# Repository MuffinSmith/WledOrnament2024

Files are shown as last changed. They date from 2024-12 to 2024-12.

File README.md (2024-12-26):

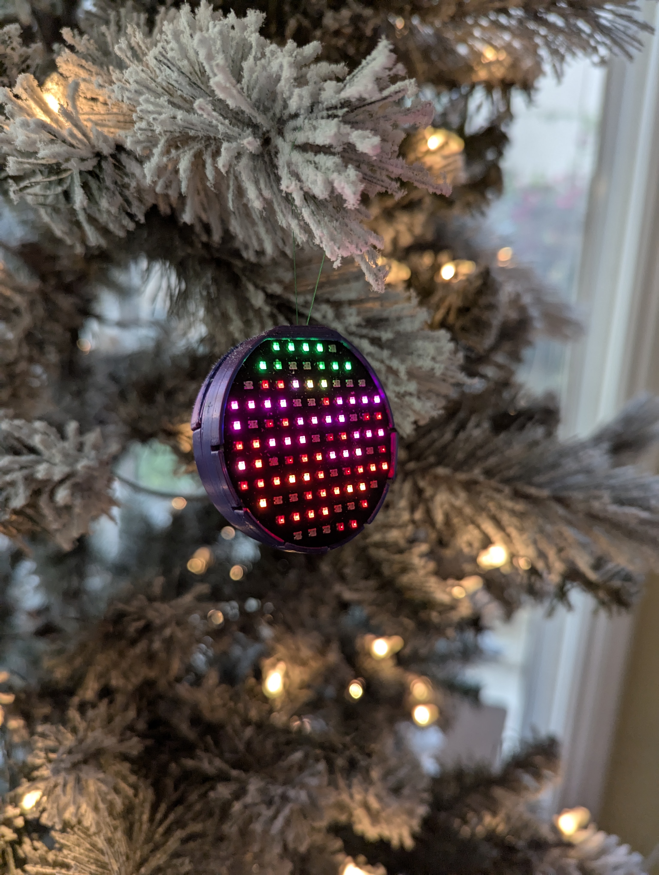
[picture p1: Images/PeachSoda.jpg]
ornament image, Peachsoda effect

# WledOrnament2024
My Christmas present for family
## Instructions
Default behavior is to shuffle all the presets.
Single button press will cycle each preset in order and stay on that preset.
Double button press will go back to shuffling the presets.
Long button press will turn off the display but leave the micro on.

Taking off the back of the ornament starts by holding it from the bottom and
squeezing the corners of the lid with one hand, while pulling at the tab on 
top with the other hand.
To put the lid back on start with the tab and slot it into the groove, then
squeeze the corners of the lid while pushing it back into place.

### Notes for improvement
buttons should be located around the edges 
I want to use soft power to turn on and off the whole device instead of a switch

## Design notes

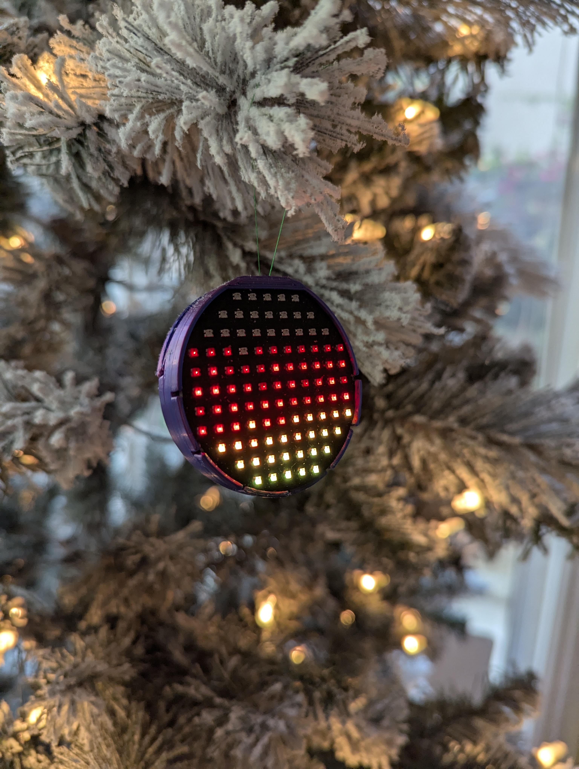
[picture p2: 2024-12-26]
Images/Candle.jpg

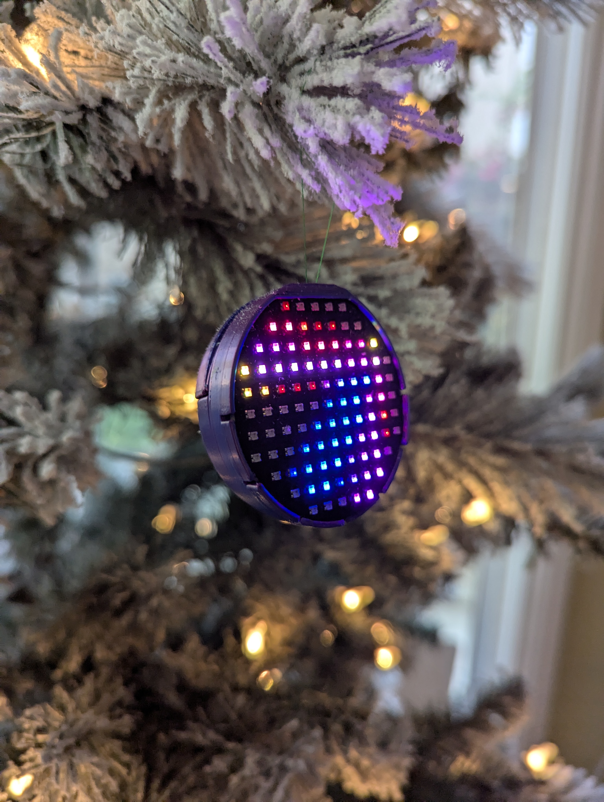
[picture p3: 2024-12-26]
Images/ColorBurst.jpg

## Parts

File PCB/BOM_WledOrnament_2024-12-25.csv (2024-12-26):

No. | Quantity | Comment | Designator | Footprint | Value | Manufacturer Part | Manufacturer | Supplier Part | Supplier
1 | 12 | 100nF | C1,C1,C1,C1,C4,C4,C4,C4,C7,C7,C7,C7 | C0402 | 100nF |  |  | C1525
2 | 20 | 22uF | C2,C2,C2,C2,C8,C8,C8,C8,C9,C9,C9,C9,C10,C10,C10,C10,C11,C11,C11,C11 | C0603 | 22uF | CL10A226MQ8NRNC | SAMSUNG(三星) | C59461 | LCSC
3 | 4 | 10uF | C3,C3,C3,C3 | C0402 | 10uF | CL05A106MQ5NUNC | SAMSUNG(三星) | C15525 | LCSC
4 | 8 | 2.2uF | C5,C5,C5,C5,C12,C12,C12,C12 | C0402 | 2.2uF | CL05A225MQ5NSNC | SAMSUNG(三星) | C12530 | LCSC
5 | 4 | 4.7uF | C6,C6,C6,C6 | C0402 | 4.7uF | CL05A475MP5NRNC | SAMSUNG(三星) | C23733 | LCSC
6 | 4 | SS34 | D1,D1,D1,D1 | SMA_L4.3-W2.6-LS5.2-RD |  | SS34 | MDD(辰达半导体) | C8678 | LCSC
7 | 4 | 4.7uH | L1,L1,L1,L1 | L0805 | 4.7uH | CMP201209UD4R7MT | FH(风华) | C139243 | LCSC
8 | 4 | 1uH | L2,L2,L2,L2 | L1206 | 1uH | CMP321609UD1R0MT | FH(风华) | C139248 | LCSC
9 | 388 | XL-1615RGBC-WS2812B | LED1,LED1,LED1,LED1,LED2,LED2,LED2,LED2,LED3,LED3,LED3,LED3,LED4,LED4,LED4,LED4,LED5,LED5,LED5,LED5,LED6,LED6,LED6,LED6,LED7,LED7,LED7,LED7,LED8,LED8,LED8,LED8,LED9,LED9,LED9,LED9,LED10,LED10,LED10,LED10,LED11,LED11,LED11,LED11,LED12,LED12,LED12,LED12,LED13,LED13,LED13,LED13,LED14,LED14,LED14,LED14,LED15,LED15,LED15,LED15,LED16,LED16,LED16,LED16,LED17,LED17,LED17,LED17,LED18,LED18,LED18,LED18,LED19,LED19,LED19,LED19,LED20,LED20,LED20,LED20,LED21,LED21,LED21,LED21,LED22,LED22,LED22,LED22,LED23,LED23,LED23,LED23,LED24,LED24,LED24,LED24,LED25,LED25,LED25,LED25,LED26,LED26,LED26,LED26,LED27,LED27,LED27,LED27,LED28,LED28,LED28,LED28,LED29,LED29,LED29,LED29,LED30,LED30,LED30,LED30,LED31,LED31,LED31,LED31,LED32,LED32,LED32,LED32,LED33,LED33,LED33,LED33,LED34,LED34,LED34,LED34,LED35,LED35,LED35,LED35,LED36,LED36,LED36,LED36,LED37,LED37,LED37,LED37,LED38,LED38,LED38,LED38,LED39,LED39,LED39,LED39,LED40,LED40,LED40,LED40,LED41,LED41,LED41,LED41,LED42,LED42,LED42,LED42,LED43,LED43,LED43,LED43,LED44,LED44,LED44,LED44,LED45,LED45,LED45,LED45,LED46,LED46,LED46,LED46,LED47,LED47,LED47,LED47,LED48,LED48,LED48,LED48,LED49,LED49,LED49,LED49,LED50,LED50,LED50,LED50,LED51,LED51,LED51,LED51,LED52,LED52,LED52,LED52,LED53,LED53,LED53,LED53,LED54,LED54,LED54,LED54,LED55,LED55,LED55,LED55,LED56,LED56,LED56,LED56,LED57,LED57,LED57,LED57,LED58,LED58,LED58,LED58,LED59,LED59,LED59,LED59,LED60,LED60,LED60,LED60,LED61,LED61,LED61,LED61,LED62,LED62,LED62,LED62,LED63,LED63,LED63,LED63,LED64,LED64,LED64,LED6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 | LED-SMD_4P-L1.6-W1.5_XL-1615RGBC-WS2812B |  | XL-1615RGBC-WS2812B | XINGLIGHT(成兴光) | C5349954 | LCSC
10 | 4 | Mark-Point | MARK1,MARK2,MARK3,MARK4 | Mark-Point-1mm
11 | 4 | MMICT390200012 | MIC1,MIC1,MIC1,MIC1 | MIC-SMD_5P-L3.5-W2.7-TL_MMICT390200012 |  | MMICT390200012 | TDK InvenSense(应美盛) | C3171752 | LCSC
12 | 4 | Battery Protection | Q1,Q1,Q1,Q1 | SOT-23-6_L2.9-W1.6-P0.95-LS2.8-BR |  | DW01 | Hottech(合科泰) | C181096 | LCSC
13 | 12 | AO3400A | Q2,Q2,Q2,Q2,Q3,Q3,Q3,Q3,Q5,Q5,Q5,Q5 | SOT-23-3_L2.9-W1.3-P1.90-LS2.4-BR |  | AO3400A | AOS | C20917 | LCSC
14 | 4 | S8050 J3Y | Q4,Q4,Q4,Q4 | SOT-23-3_L3.0-W1.7-P0.95-LS2.9-BR |  | S8050 J3Y | CJ(江苏长电/长晶) | C2146 | LCSC
15 | 4 | 2kΩ | R1,R1,R1,R1 | R0402 | 2kΩ | 0402WGF2001TCE | UNI-ROYAL(厚声) | C4109 | LCSC
16 | 4 | 100kΩ | R2,R2,R2,R2 | R0402 | 100kΩ | 0402WGF1003TCE | UNI-ROYAL(厚声) | C25741 | LCSC
17 | 4 | 22kΩ | R3,R3,R3,R3 | R0402 | 22kΩ | 0402WGF2202TCE | UNI-ROYAL(厚声) | C25768 | LCSC
18 | 4 | 100Ω | R4,R4,R4,R4 | R0402 | 100Ω | 0402WGF1000TCE | UNI-ROYAL(厚声) | C25076 | LCSC
19 | 4 | 1kΩ | R5,R5,R5,R5 | R0402 | 1kΩ | 0402WGF1001TCE | UNI-ROYAL(厚声) | C11702 | LCSC
20 | 4 | 10kΩ | R6,R6,R6,R6 | R0402 | 10kΩ | 0402WGF1002TCE | UNI-ROYAL(厚声) | C25744 | LCSC
21 | 4 | On | Off | SW1,SW1,SW1,SW1 | SW-SMD_SS-3235S-L3.00 |  | SS-3235S-L3 | XKB Connectivity(中国星坤) | C381098 | LCSC
22 | 4 | TS-1002S-09026C | SW2,SW2,SW2,SW2 | KEY-SMD_4P-L6.0-W6.0-P4.50-LS9.5-BR |  | TS-1002S-09026C | XUNPU(讯普) | C455118 | LCSC
23 | 4 | ESP32-C3 SuperMini | U1,U1,U1,U1 | ESP32-C3 SuperMini SMT
24 | 4 | Cake Battery | U3,U3,U3,U3 | Cake Battery
25 | 4 | 5v Boost | U5,U5,U5,U5 | WSON-6_L2.0-W2.0-P0.65-TL-EP |  | TPS61240DRVR | TI(德州仪器) | C59567 | LCSC
26 | 4 | Battery charger | U7,U7,U7,U7 | SOT-23-6_L2.9-W1.6-P0.95-LS2.8-BL |  | TP4057 | TPOWER(天源) | C440390 | LCSC
27 | 4 | 3.3 buck | U8,U8,U8,U8 | SOT-23-6_L2.9-W1.6-P0.95-LS2.8-BR |  | SM8102ABC | silergy(矽力杰) | C479069 | LCSC

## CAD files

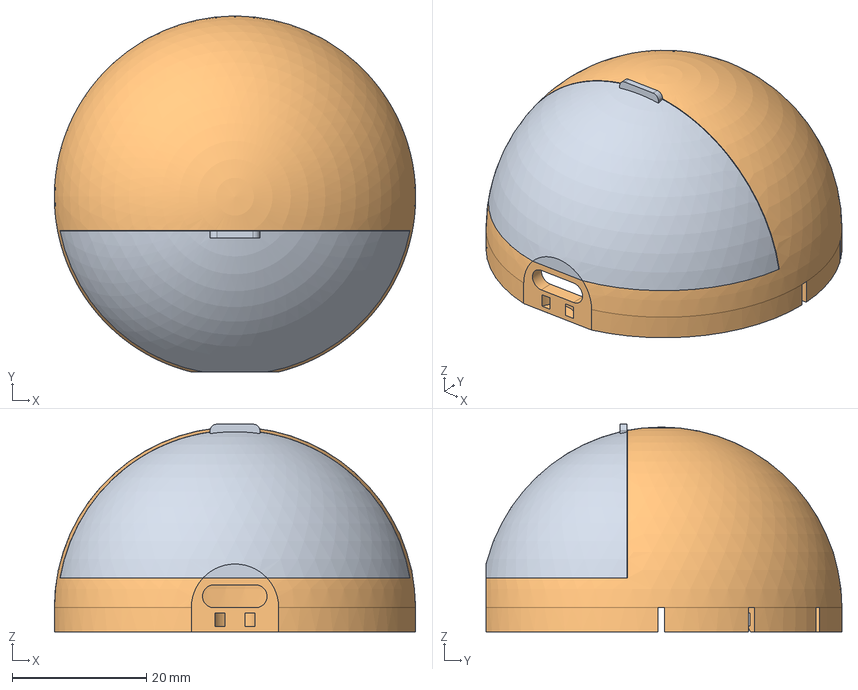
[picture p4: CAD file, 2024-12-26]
3D Files/Ornament Enclosure v15.step
53.8 x 53.0 x 30.9 mm

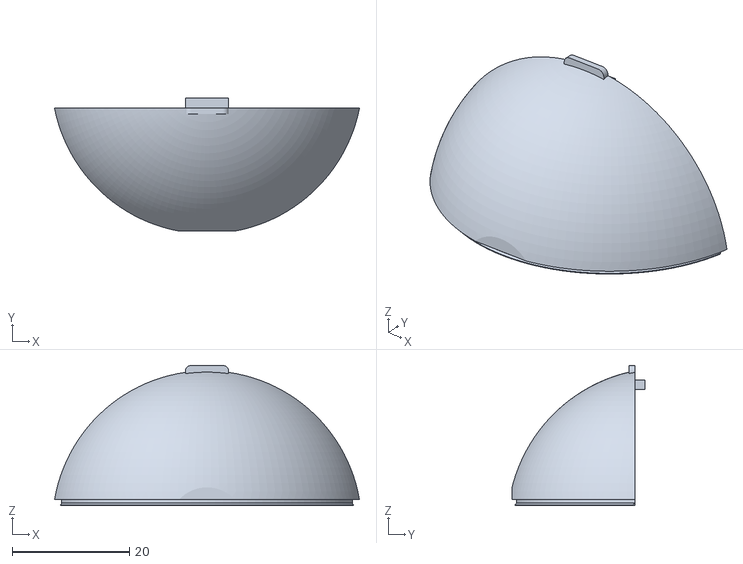
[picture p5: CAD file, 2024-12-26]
3D Files/Ornament Lid.stl
52.0 x 22.7 x 23.9

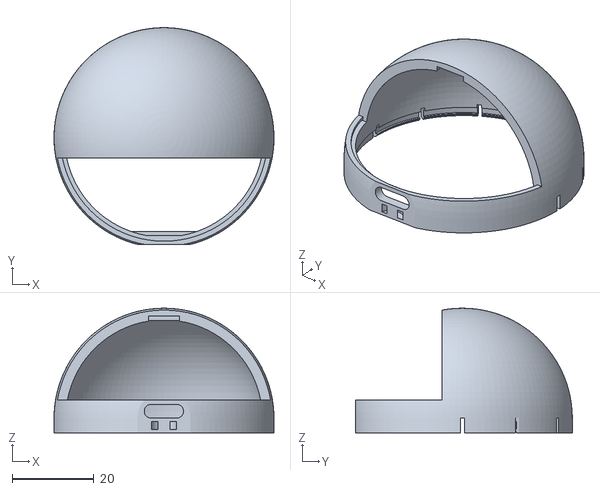
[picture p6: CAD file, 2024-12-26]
3D Files/Ornament Case.stl
53.8 x 53.0 x 30.5

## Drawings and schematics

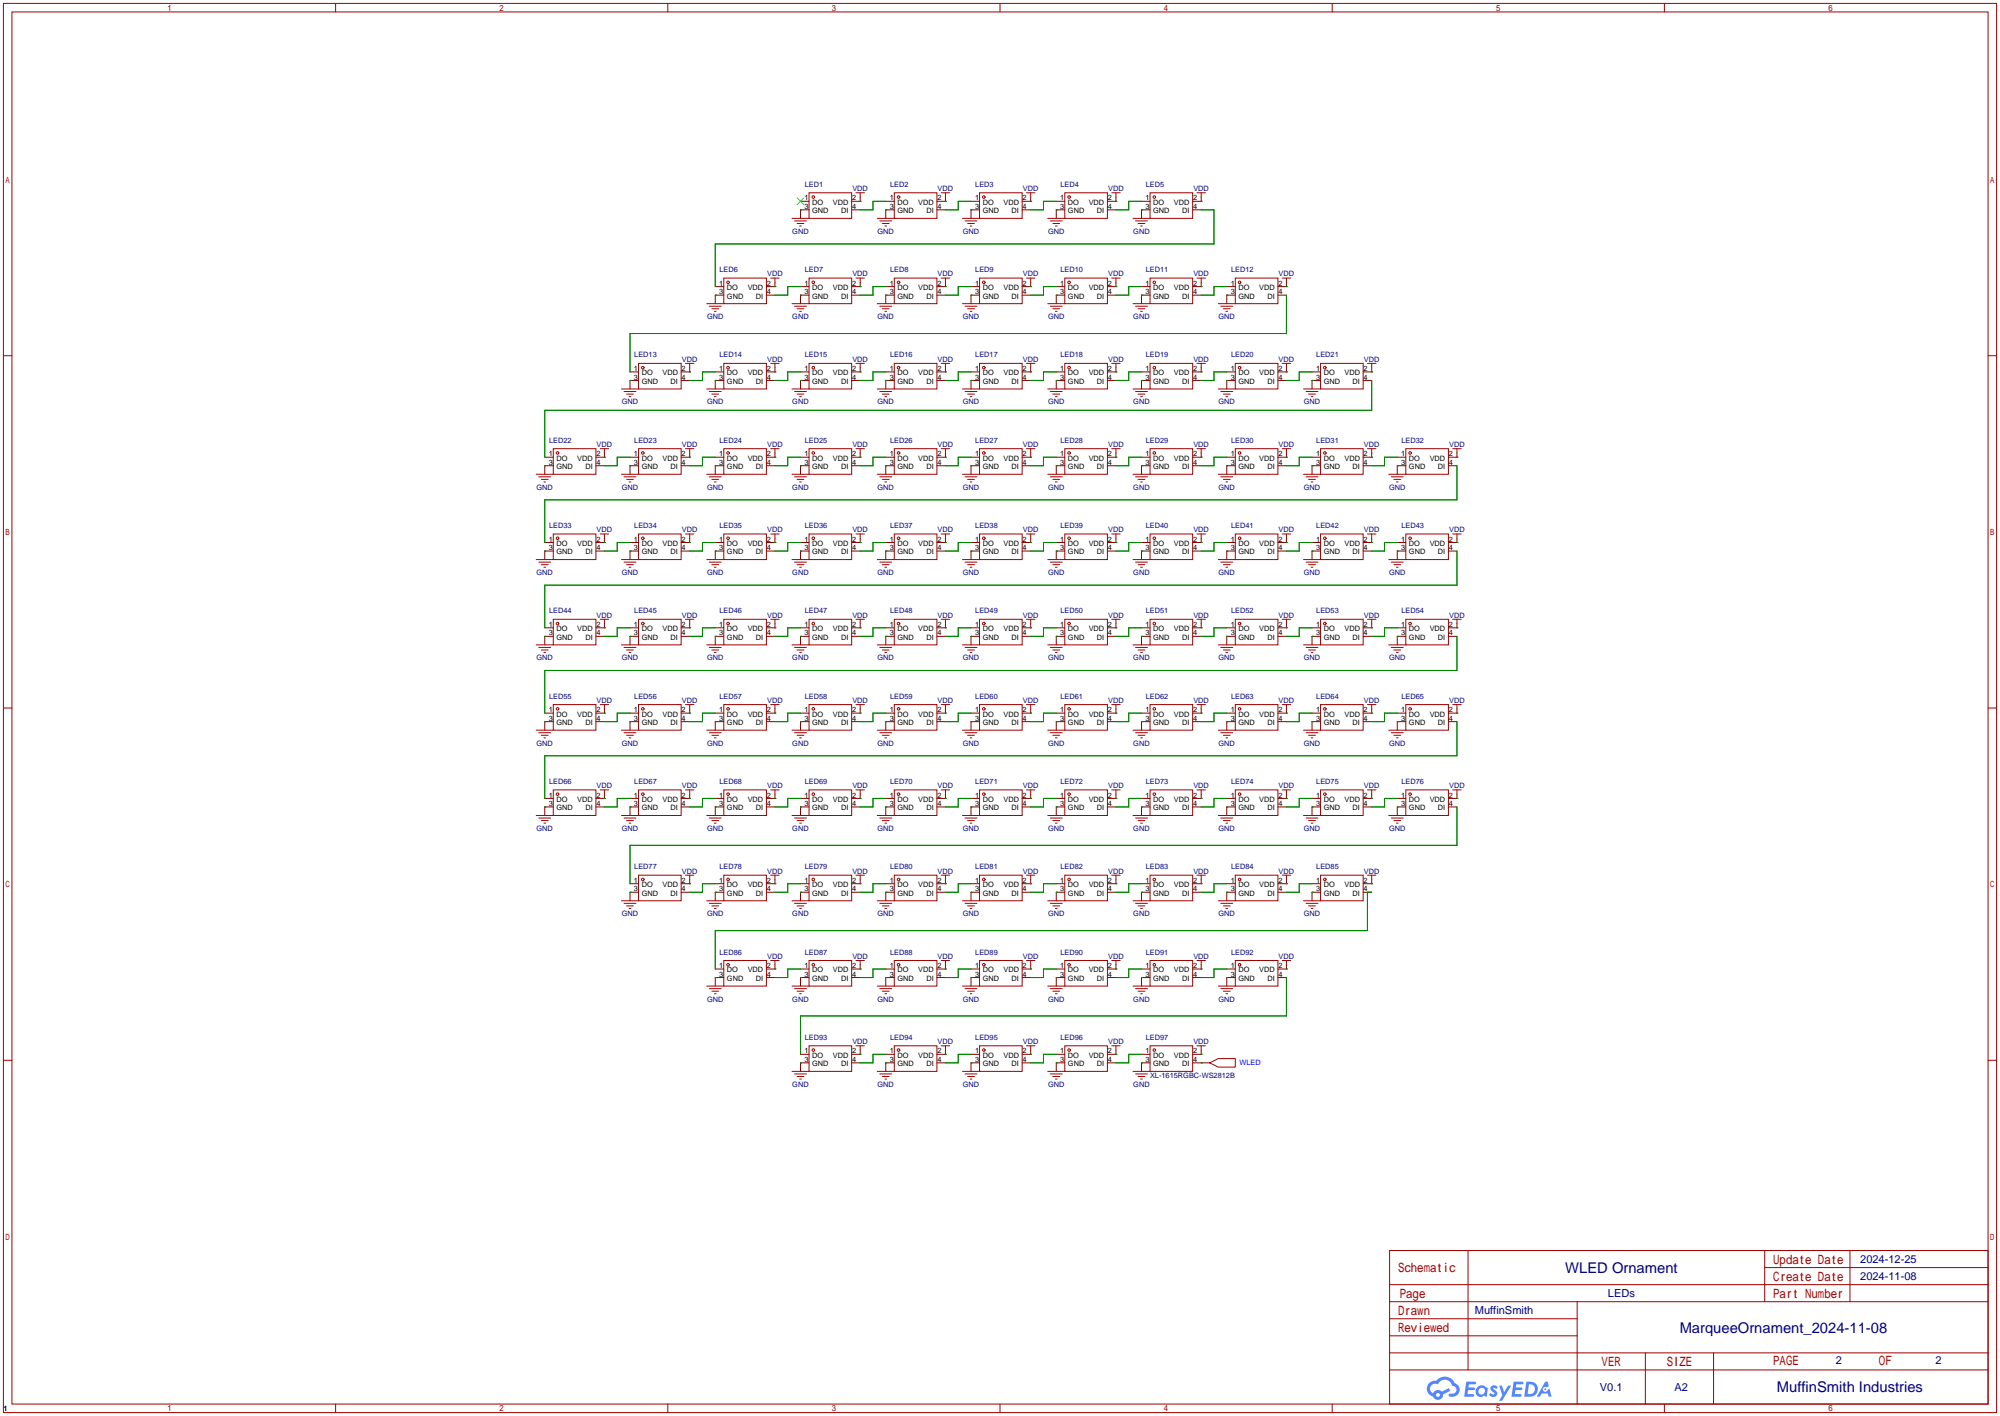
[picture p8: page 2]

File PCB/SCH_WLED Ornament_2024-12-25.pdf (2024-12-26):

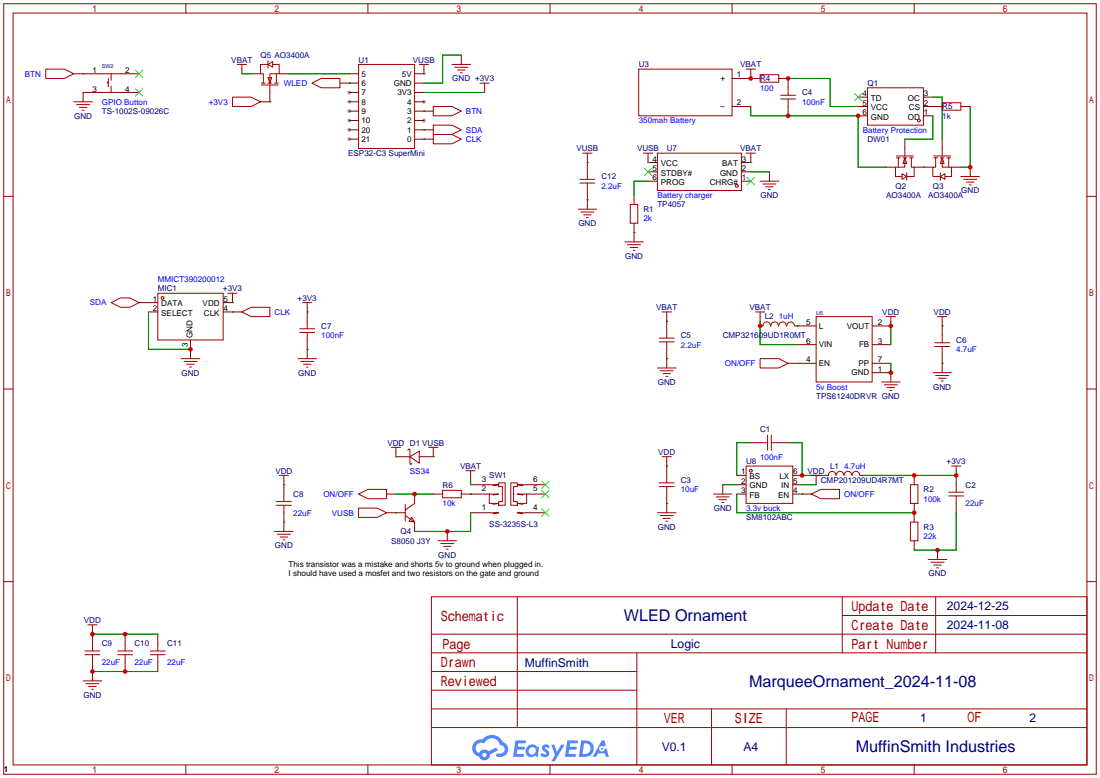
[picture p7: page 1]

GND
This transistor was a mistake and shorts 5v to ground when plugged in.
I should have used a mosfet and two resistors on the gate and ground
